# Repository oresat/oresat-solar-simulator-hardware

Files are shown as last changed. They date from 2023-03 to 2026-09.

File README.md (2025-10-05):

# oresat-solar-simulator-hardware

The hardware repository for our solar simulator for testing [OreSat 1U solar panels](https://github.com/oresat/oresat-solar-hardware)

## General Information

The OreSat Solar Simulator is a benchtop simulator for hardware-in-the-loop testing of CubeSat solar modules. It uses LED and halogen light bulbs to emit light that simulates the sun's solar spectrum in low Earth orbit (Air Mass 0 or 'AM0').

The work for this was done as an MCECS Capstone Project from January to June of 2023 by Bendjy Faurestal, Adam Martinez, Cesar Ordaz-Coronel, and Charles Nasser. Andrew Greenberg was both representing PSAS as the Industry Sponsor and the Faculty Advisor to the students.

## Hardware
Controller board top:
controller-board-top
Bottom:
controller-board-bottom

The schematic and pcb layout were designed in [kiCAD](https://www.kicad.org/download/). The boards we used were fabricated by [OSHPark](https://oshpark.com/) in Lake Oswego, OR.

The simulators are driven by a Raspberry Pi Pico attached to the board.

## Software

The software for this project lives in the [oresat-solar-simulator-software](https://github.com/oresat/oresat-solar-simulator-software) repository.

## Mechanical

The mechanical components were developed by Zeus Ayala using onShape.

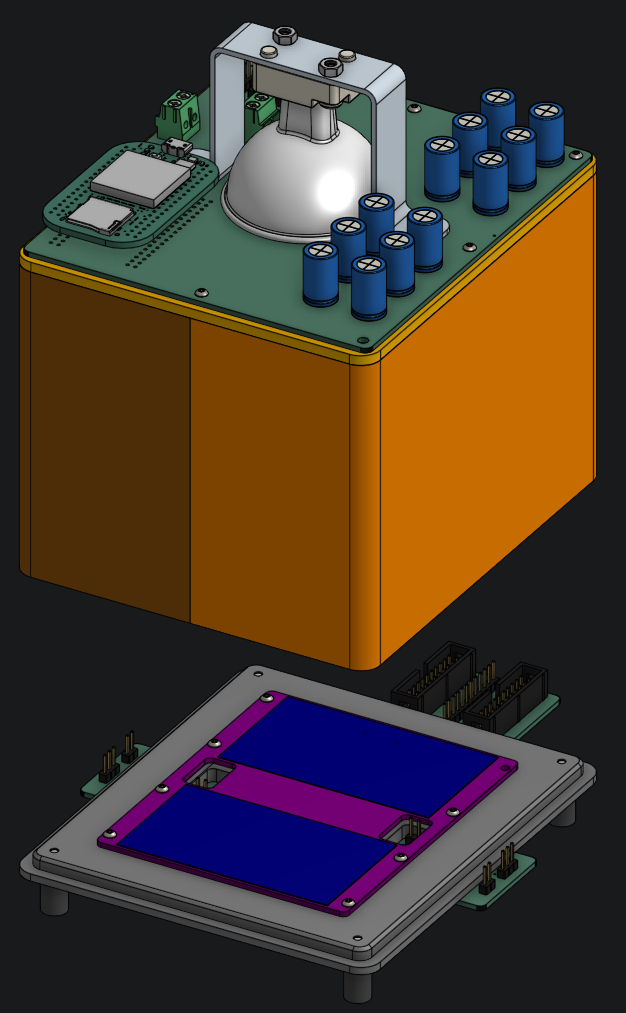
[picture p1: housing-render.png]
housing


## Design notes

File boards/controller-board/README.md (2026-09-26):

---
title: "**OreSat Solar Simulator Board**"
subtitle: |
  **Fabrication and Assembly Information**\
  For build TIME-STAMP
fontsize: 10pt
geometry:
  - margin=0.5in
toc: true
toc-depth: 2
colorlinks: true
urlcolor: blue
---

\newpage

# About this Board

## Board Description

The OreSat Solar Simulator board provides a simulated 1.33 kw/m^2 of pseudo sunlight to a 1U Oresat solar module.

MOAR HERE.

## Documentation Links

- Git repository: <https://github.com/oresat/oresat-solar-simulator-hardware>
- **TODO:** Design Notes + Design Review Notes

## Documentation Files

| Filename | Notes |
| --- | --- |
| README.pdf | This README file |
| PROJECT-NAME-outline.dxf | Board outline (with holes) in DXF format |
| PROJECT-NAME-pcba.step | 3D model of PCBA (with components) |
| PROJECT-NAME-render-bot.jpg | Render of the top of the 3D model |
| PROJECT-NAME-render-bot.jpg | Render of the bottom of the 3D model |
| PROJECT-NAME-schematic.pdf | PDF of board schematics |

## Contact Information

- Website: <https://www.oresat.org/>
- Email: <oresat@pdx.edu>
- Instagram: @pdxaerospace

## Board Renders

Render of the top of the 3D model
Render of the bottom of the 3D model

\newpage

# Printed Circuit Board (PCB) Fabrication Information

## Board Info

- 4 layer board
- Bounding box is TBD mm
- Board thickness is 1.59 mm

## Board Requirements

- Design Rules
    - Minimum Trace / Space design rules
       - Outer layers: 0.127 mm (5.0 mil) / 0.127 mm (5.0 mil)
       - Inner layers: 0.127 mm (5.0 mil) / 0.127 mm (5.0 mil)
    - Outer dimension router tolerance: +/- 0.254 mm (10.0 mil)
    - Hole placement tolerance: +/- 0.075 mm (3.0 mil)
    - Inner tab routed slot tolerance: +/- 0.254 mm (10.0 mil)
- Drills
   - Drill Positional Tolerance: 0.051 mm (2.0 mil)
   - Drill Size tolerance: +/- 0.064 mm (2.5 mil)
- Plated/Un-plated holes
  - Via/PTH minimum diameter: 0.254 mm (10 mil)
  - Via/PTH minimum annulus: 0.102 mm (4 mil) radius
- Outline/Routing
  - Requires a 1.0 mm or smaller diameter routing bit
- Slots
  - There are 7 plated slots slots.
- Cutouts
  - There are no cutouts
- There are 3 fiducials on the top layer.
- Panel tabs ("mouse bites")
   - Card edges must be smooth; no mouse bites or other intrusions into the card outline.
   - If external mouse bites are required, minimize and customer will remove by hand before assembly.
- If not otherwise specified, build to IPC 6012 Class 2 or better.

## Stackup /  Materials

- Outside copper layers is 1 oz Cu after plating (0.043 mm / 1.7 mil)
- Inside copper layers are 0.5 oz Cu (0.018 mm / 0.7 mil)
- There are no requirements on the prepreg or core of this four layer stackup.
- Board Surface treatment should be ENIG, although immersion Silver is acceptable.
- White silkscreen on top and bottom surface
- Taiyo PSR-4000 or equivalent soldermask on top and bottom, no requirements for color.

## Array / Panel Information

- Coordinate with Contract Manufacturer (CM) for optimal size of this panel.
- If no feedback from CM, then produce single boards (no panel).

## Fabrication Files

### IPC-2581 File

| Filename | Notes |
| --- | --- |
| PROJECT-NAME-ipc2581.xml | IPC-2581 board information file |

### Legacy PCB Files

| Filename | Notes |
| ---| --- |
| PROJECT-NAME-Edge_Cuts.gbr | RS274X file for the dimension (outline) layer |
| PROJECT-NAME-F_Silkscreen.gbr | RS274X file for the top silkscreen |
| PROJECT-NAME-F_Mask.gbr | RS274X file for the top soldermask |
| PROJECT-NAME-F_Cu.gbr | RS274X file for the top copper layer |
| PROJECT-NAME-In1_Cu.gbr | RS274X file for the layer 2 copper |
| PROJECT-NAME-In2_Cu.gbr | RS274X file for the layer 3 copper |
| PROJECT-NAME-B_Cu.gbr | RS274X file for the bottom copper layer |
| PROJECT-NAME-B_Mask.gbr | RS274X file for the bottom soldermask |
| PROJECT-NAME-B_Silkscreen.gbr | RS274X file for the bottom silkscreen |
| PROJECT-NAME-NPTH.drl | Excellon file for non-plated through holes |
| PROJECT-NAME-PTH.drl | Excellon file for plated through holes | 

\newpage

# Printed Circuit Board Assembly (PCBA) Information

## Assembly Info

- All components are on the top side of the board.
- This PCBA is mostly surface mount (SMT) with a few (THT) components.

## Assembly Requirements

- Assemble to IPC Class 2 or better
- Bake components that are not moisture sealed to appropriate levels as required.
- Any solder paste (leaded or RoHS) is acceptable. RoHS solder is slightly preferred.
- Any no-clean or aqueous was flux is acceptable.
- No conformal coating.
- Ship in antistatic protective bag

## Component Specific Assembly Information

- No specific information

## Hand Placement Instructions

- Stencil, place, and reflow back (LEDs) first.
- Press in HW1,2,7,8 press-fit nuts in order to protect LEDs on back side.
- Stencil, place, and reflow the top.
- Hand solder the through hole components (connectors).
- Use thermal glue or thermal epoxy to glue down heatsinks, one per LED.
- Use a minimal amount of glue, and use drop-in-the-middle technique to avoid air pockets.

## Assembly Files

### IPC-2581 File

| Filename | Notes |
| --- | --- |
| PROJECT-NAME-ipc2581.xml | IPC-2581 board information file |

### Bill of Materials (BOM)

| Filename | Description |
| --- | --- |
| PROJECT-NAME-bom.csv | BOM in Comma Separated Variable format |

### Solder Paste Stencils

| Filename | Notes |
| --- | --- |
| PROJECT-NAME-B_Paste.gbr | RS274X file for top/front solder paste stencil |
| PROJECT-NAME-F_Paste.gbr | RS274X file for bottom/back solder paste stencil |

### Mounting/Placement Location

| Filename | Description |
| --- | --- |
| PROJECT-NAME-3u.pos | Pick and place locations for components |

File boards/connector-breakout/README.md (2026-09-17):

# OreSat FlatSat

A "flatsat" is a integration and debugging configuration of your satellite that allows you to more easily do system integration, software development, testing, and debugging. It's the "open" satellite that allows you to get at all the signals and ports.

Here's what our OreSat0 flatsat looks like -- note the cards laid out flat on the table, the power supply on the left, the ribbon cable and cards, and the small PC on the upper right (vertical wall) that interfaces everything to the interwebs.

OreSat 1U Backplane Picture

Here's a closeup of the cards: the 40 wire ribbon cable mimics our backplane, the "flatsat breakout boards" interface the cards to the ribbon cable backplane, and the "card debug boards" at the bottom of some of the cards are JTAG, serial, USB, and some spare GPIO that's common to all cards.

OreSat 1U Backplane Picture

# Some notes

- We ordered 6 inch ribbon cables, but had to cut them down to 4" to pack the cards on our small table. We did that by cutting the ribbon cable and pressing on an IDC connector.
- Don't forget to add termination resistors to both sides of the ribbon cable.
- The "exteranal supply shutdown" board kills the external power supply when the watchdog (or inhibit switches) pull the !SHUTDOWN signal low.
- You need very flexible USB micro cables for this to work well.
- FFCs suck. But, they're still better than anything else.

# LICENSE

Copyright the Portland State Aerospace Society 2021.

This source describes Open Hardware and is licensed under CERN-OHL-S v2 or any later version.

You may redistribute and modify this source and make products using it under the terms of the CERN-OHL-S v2 (https://ohwr.org/cern_ohl_s_v2.txt).

This source is distributed WITHOUT ANY EXPRESS OR IMPLIED WARRANTY, INCLUDING OF MERCHANTABILITY, SATISFACTORY QUALITY AND FITNESS FOR A PARTICULAR PURPOSE. Please see the CERN-OHL-S v2 for applicable conditions.

Source location: https://github.com/oresat/

As per CERN-OHL-S v2 section 4, should You produce hardware based on this source, You must where practicable maintain the Source Location visible on the external case of the Gizmo or other products you make using this sourc

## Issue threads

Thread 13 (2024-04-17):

Hardware update ideas for later

venomboss985, 2024-04-17:
- Change the Pocketbeagle headers to Pico headers (options for surface mounting or header pins)
- Hardware enable/disable switch for UV LEDs (safety)
- Inrush current capacitor on the halogen bulb
- PD power supply?
- Hardware switch for Pico to be powered from USB or solar sim power supply
- Flyback diode for the halogen

andrewgreenberg, 2025-04-11:
Switched to Pico, no more UV LEDs, better caps on halogen bulb, PD supply a good idea but too late, Pico is only powered by USB, and the flyback was added. Closing!

Closed 2025-04-11.

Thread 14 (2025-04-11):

v2.0: ZOMG the diodes are backwards

andrewgreenberg, 2025-04-11:
WTAF, the datasheet gives the anode/cathode markings on an UPSIDE DOWN package. All LEDs on this god damn board are backwards.

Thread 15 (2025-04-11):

Halogen's P MOSFET pull up too weenie

andrewgreenberg, 2025-04-11:
The halogen bulb's P CH MOSFET gets turned on just fine, but couldn't turn off fast enough for a 50 KHz PWM. We switched it down to 5 KHz and changed the serial gate resistor to 22 ohms and the pull up to 100 ohms.

This works, but frankly, it may be worthwhile to just switch to a gate driver chip like we did originally (but for a P channel, not N channel).

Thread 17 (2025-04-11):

LEDs get all sorts of damaged during build

andrewgreenberg, 2025-04-11:
The LEDs on the bottom of the board are really sensitive to chipping. Protect the bottom side better after LED reflow. Maybe some standoffs?

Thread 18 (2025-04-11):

Read the current back from each string?

andrewgreenberg, 2025-04-11:
Maybe let the Pico read the current back from each LED string by adding an opamp off of the 50 mOHm shunt that the MPS uses. That would give the Pico direct closed loop control over the LED brightness in theory.

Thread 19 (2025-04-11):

LED fuse should be 12A; double check everything else

andrewgreenberg, 2025-04-11:
6 LED strings @ 2 A each = 12 A, duh. But can the fuse holder handle that? How about the connectors? Etc.

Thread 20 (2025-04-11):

Some LEDs on when Pico is unplugged from USB

andrewgreenberg, 2025-04-11:
When the Pico is plugged in then unplugged, some of the LEDs turn on. The DAC is unpowered at this point, so ???? Maybe either a stiffer pull down, or something active to pull down the DIM lines on the MPSes if there's no 3.3V?

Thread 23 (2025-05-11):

+/- markings on PCB are wrong for 12V input

andrewgreenberg, 2025-05-11:

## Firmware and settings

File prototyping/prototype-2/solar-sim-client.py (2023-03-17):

import socketio
import Adafruit_BBIO.PWM as PWM
import Adafruit_BBIO.GPIO as GPIO
from time import sleep

server_addr='192.168.1.66' 

with open('server.conf') as f:
    server_addr=f.read() 

BB_FREQ = 250e3
LED_PIN = "P9_14"
sio = socketio.Client(logger=True, engineio_logger=False)
GPIO.setup(LED_PIN, GPIO.OUT)


@sio.event
def connect():
    print('connected to server')
    
    
@sio.event
def connect_error(data):
    print("The connection failed!")


@sio.event
def disconnect():
    print('disconnected from server')


#this event gets the from the sever and execute or
#emit a response to the server 
@sio.event
def cmd(msg):
    print(msg)
    if msg == 'ON':
        print("LED Should Be on")
        # Turn LED on
        GPIO.setup(LED_PIN, GPIO.OUT)
        GPIO.output(LED_PIN, GPIO.HIGH)
        sleep(0.5)
    if msg == 'PWM':
        print("LED Should Be PWM'ing")
        # Simulate Transition
        # Gradually adjust the PWM to 0
        for i in range(100, 0, -1):
            PWM.start(LED_PIN, i, BB_FREQ)
            sleep(0.1)
        sleep(.5)
        PWM.cleanup(LED_PIN)
    if msg == 'OFF':
        print("LED Should Be OFF")
        sleep(0.5)
        PWM.stop(LED_PIN)
        PWM.cleanup(LED_PIN)
        GPIO.setup(LED_PIN, GPIO.OUT)
        GPIO.output(LED_PIN, GPIO.LOW)
    if msg == 'GET_TEMP':
        dummyTemp = 34
        print('Sending temp...')
        print(dummyTemp)
        sio.emit('my message', {'foo': 'bar'}, namespaces='/chat')
        #sio.emit(data =str, dummyTemp)
        #sio.emit('cmd',"dummyTemp")
    if msg == 'GET_LIGHT_LEVEL':
        print('Sending entenaity')
    else:
        sio.wait()
    

if __name__ == '__main__':
    sio.connect(f'http://{server_addr}:8080')
    sio.wait()
    #hello()

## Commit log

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2023-03-10 fixed string issue with client
    [solar-sim-client.py]
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2023-04-20 Updated controller board and added BOM
    [controller-board-bom.xlsx, controller-board.kicad_pcb, controller-board.kicad_sch]
2023-04-20 Added silk screen name/date
    [controller-board.kicad_pcb]
2023-04-20 added stl for v2 of hood
    [top-model-v0.2.stl]
2023-04-21 Added soldermask openings for heat sinks
    [controller-board.kicad_pcb]
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2023-04-21 Updated mounting holes and fixed some errors
    [controller-board.kicad_pcb]
2023-04-21 Added initial sensor board schematic
    [sensor-board.kicad_pcb, sensor-board.kicad_sch]
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2023-05-22 Updated main PCB. Added lots of LEDs and moved things around. Fixed some issues.
    [controller-board.kicad_pcb, controller-board.kicad_sch]
2023-05-26 Updated board design/layout and added step file
    [controller-board.kicad_pcb, controller-board.kicad_sch]
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2023-05-26 Added thermal vias for LEDS and soldermask openings to bypass the LEDs
    [controller-board.kicad_pcb, controller-board.kicad_sch]
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2023-06-14 fixed global variable bug and PWMdata
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2023-08-23 fixed typo and added 3as4 sample
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2024-01-24 Fixed schematic overflow
    [controller-board.kicad_sch]
2024-01-24 Fixed library paths on controller board
    [controller-board.kicad_sch]
2024-01-25 compleded v1.0 adapter for raspberry pi pico to pocket-beagle socket (on solar sim controller board)/
    [pico-pb-adapter.kicad_pcb, pico-pb-adapter.kicad_sch]
2024-01-25 compleded v1.0 adapter for raspberry pi pico to pocket-beagle socket (on solar sim controller board)
    [pico-pb-adapter.kicad_pcb, pico-pb-adapter.kicad_sch]
2024-05-03 Small changes for production, maybe? And upgraded to KiCAD 8.
    [pico-pb-adapter.kicad_pcb, pico-pb-adapter.kicad_sch]
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2024-06-28 fixed footprints for some components
    [controller-board.kicad_pcb, controller-board.kicad_sch]
2024-06-29 moved LED driver circuitry to front layer of PCB
    [controller-board.kicad_pcb, controller-board.kicad_sch]
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2024-06-30 Fxied halogen PWM, made SPS DNP, some schematic polishing.
    [controller-board.kicad_sch]
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2024-07-01 added vias, changed ground pads to solid on some components, anadjusted tracks
    [controller-board.kicad_pcb]
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2024-07-12 added ground vias and changed ground pad filling on some components
    [controller-board.kicad_pcb]
2024-07-12 condensed 3-pin and 2-pin connectors to controller board into one 4-pin connector
    [sensor-board.kicad_pcb, sensor-board.kicad_sch]
2024-07-18 added new design for LED driver portion of circuit with A6214
    [controller-board.kicad_pcb, controller-board.kicad_sch]
2024-07-26 added project for test board for new LED driver
    [A6214 Test Board.kicad_pcb, A6214 Test Board.kicad_sch, controller-board.kicad_pcb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]
2024-07-28 finished test board for A6214 and created files for printing
    [A6214 Test Board.kicad_pcb, A6214 Test Board.kicad_sch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]
2024-07-29 edited schematic to include new LED driver on new page
    [controller-board.kicad_sch, untitled.kicad_sch]
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2024-08-14 redesigned pcb
    [controller-board.kicad_pcb, controller-board.kicad_sch, untitled.kicad_sch]
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2024-08-16 minor changes to tracks and zones on controller pcb
    [controller-board.kicad_pcb]
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2024-08-21 added pull-down resistor to ADIM pins on LED drivers, completed BOM, reorganized schematic, switched 10k resistors and thermistors, added datasheets, split 12V pwr supply and added additional fuse, c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
    [controller-board.kicad_pcb, controller-board.kicad_sch, led-drivers.kicad_sch]
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2024-08-22 removed 100k pull-down resistors from LED drivers and added a 100k resistor to each output of DAC, other misc schematic and pcb changes
    [controller-board.kicad_pcb, controller-board.kicad_sch, led-drivers.kicad_sch]
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2024-08-27 Andrew polishing: arbitrary schematic changes to make it pretty, and then updating zones to have fillets and smaller widths, and a billion ground vias.
    [controller-board-bom.xlsx, controller-board.kicad_pcb, controller-board.kicad_sch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]
2024-08-28 Moved to a four layer board because this is a pretty packed and power hungry board, the power planes will make everything so much better. Also started on via cleanup.
    [controller-board.kicad_pcb]
2024-08-28 replaced led footprints for UV lights
    [controller-board.kicad_pcb, led-drivers.kicad_sch]
2024-10-21 Move schematics off of root page onto its own sheet. Rename sheets to be oresat standard naming convention. Clean up 0603 and 0402 footprints to be oresat passives. Sort BOM by footprint. Clean up si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
    [controller-board-pico.kicad_sch, controller-board-sch-leds.kicad_sch, controller-board-sch-pico.kicad_sch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]
2025-01-13 completed layout for new LED drivers in schematic
    [controller-board-pico.kicad_sch, controller-board-sch-leds.kicad_sch]
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2025-02-03 modified pcb layout: rotated halogen circuitry block and moved power input for halogen closer to light halogen light, moved thermistor block, moved power input pin onto zone connecting to halogen blo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
    [controller-board-pico.kicad_sch, controller-board-sch-leds.kicad_sch, controller-board.kicad_pcb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]
2025-02-17 v2 layout. Finally found a way to route the boards with a hopefully decent heatsink. To do: route the other side of the board, add the heatsink to the BOM.
    [A6214 Test Board.kicad_pcb, A6214 Test Board.kicad_sch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]
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2025-02-25 Update to KiCAD 9; fix library issue in oresat-ics, update ERC exclusions
    [controller-board-pico.kicad_sch, controller-board-sch-leds.kicad_sch, controller-board.kicad_pcb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]
2025-03-24 Updated 3D models, ground stitching, zone layout, lots of polishing and checking before fab.
    [controller-board-pico.kicad_sch, controller-board-sch-leds.kicad_sch, controller-board.kicad_pcb]
2025-03-24 Updates to sch and brd after fab. Fixed J6 part number, updated EOL parts to newer part numbers.
    [controller-board-pico.kicad_sch, controller-board.kicad_pcb]
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2025-09-23 Update README with correct board render URLs.
2025-10-21 Fixed the diode footprints and rotated the board Rotated the board to fit the footprints and started initial rerouting and cleanup.
    [controller-board.kicad_pcb]
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2025-10-22 Cleaned up silkscreen a bit and removed some useless tracks
    [controller-board.kicad_pcb]
2025-10-26 add more vias and more vias and more vias and some zones
    [controller-board.kicad_pcb]
2025-10-27 Reverted changes back to original layout
    Fixed diode footprint, flipped the diodes, moved ground vias and rerouted the
    traces.
    Reverted to an commit and did some weird things to get these changes up to
    master.
    [controller-board.kicad_pcb]
2025-10-30 Fixed DRC Errors, moved gnd vias slightly to do so
    [controller-board.kicad_pcb]
2026-08-31 rm photodiode, switch power terminals, 2->1 fans
    * No longer using the sensor boards will just move direct connections with
    thermisters taped down on bottom stand.
    * Switch screw terminals to banana jacks and added jank symbol, stil WIP
    on the footprint
    * Change from two smaller fans to one larger overhead fan, removing the
    drawings of the outer wings
    [controller-board-pico.kicad_sch, controller-board-sch-leds.kicad_sch, controller-board.kicad_pcb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]
2026-08-31 Change MCU, Power terminal, and relayout PCB
    * From a pi pico we change to a RP-2040 xiao MCU which has smaller
    footprint and USB-C
    * Remove the previously added banana cables and go with 6PIN molex
    receptacle to match the needed 12V DC powersupply we intend to use.
    * With the above changes relaid out the PCB
    - No current ERC nor DRC errors of note
    [controller-board-pico.kicad_sch, controller-board.kicad_pcb, controller-board.kicad_sch]
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2026-08-31 Cleanup, chg pin header footprint and xiao seed symbol
    * Cleanup:
    - Silkscreen changed to variable values
    - added power supply digikey link in schematic
    * Fan Pin header
    - added values in properties
    - caught mistake in footprint original footprint mismatching pin
    values
    - changed footprint to kicad generic 4-pin fan pin header
    * Edited xiao seed manufacturer symbol to be less ugly
    - Pin spacing is closer
    - Overall symbol is now smaller
    [controller-board-pico.kicad_sch, controller-board.kicad_pcb]
2026-09-14 Clean up library links, fix ERC errors, dix DRC errors, add more 3D models, and add makefile and readme.
    [controller-board-pico.kicad_sch, controller-board-sch-leds.kicad_sch, controller-board.kicad_pcb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]
2026-09-14 Added LED test points. Added heatsinks and notes on thermal paste. Cleaned up bottom traces with new LED test points. Some hierarchical labels, some cleanup of schematic and layout. Builds.
    [controller-board-pico.kicad_sch, controller-board-sch-leds.kicad_sch, controller-board.kicad_pcb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]
2026-09-14 v2.1 out the door! Fixed BOM, last minute double checks
    [controller-board-pico.kicad_sch, controller-board.kicad_pcb]
2026-09-14 Schematic and footprints done for rev of solar sim connector board
    [connector-breakout.kicad_pcb, connector-breakout.kicad_sch, controller-board-bom.xlsx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]
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2026-10-13 Solar Simulator Connector Board v1.1
    Recovered missing holes, added fiducials, brought up to modern standards with stackup, makefile, and readme, fixed stiching and date, checked BOM, should be good to go.
